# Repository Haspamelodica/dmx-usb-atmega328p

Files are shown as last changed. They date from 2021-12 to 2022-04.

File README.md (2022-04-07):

# DMX-USB interface running on an Atmega328p

This is an Arduino project implementing an USB-DMX interface compatible with [QLC+](https://qlcplus.org/).
It uses a rewritten port of [UDMX](https://github.com/mirdej/udmx) for implementing DMX,
and [VUSB](https://www.obdev.at/products/vusb/index.html) for implementing USB.

You don't need experience with Arduino, C or C++ to build this; I tried to explain every step without requiring prior knowledge in those areas.
However, you do need experience in soldering and building small circuits.

## Split mode

The interface can be used with one or with two Atmegas. Using two Atmegas is called "split mode".
If split mode is disabled, which is the default, the interface will be very choppy.

## Interface variants

There are two variants of the interface, differing in what protocol they use to communicate with the host.
Both can be used with or without split mode.

### UDMX-based interface

This variant works with the the (preinstalled) UDMX plugin of QLC+,
by porting the [UDMX USB-DMX interface]((https://anyma.ch/research/udmx/)) to Atmega328p.

On Windows, the [libusbK driver](https://www.illutzminator.de/udmxdriver.html) needs to be installed for this to work.
This repository contains a copy of the driver software: `uDMX_Driver_libUSBK.zip`.
(If you don't want to install a driver, use the HID-based interface, which works without a driver.)

### HID-based interface

Works with the (preinstalled) HID plugin of QLC+, by using the same protocol
as the [FX5](http://fx5.de/) and [Digital Englightment](http://www.digital-enlightenment.de/usbdmx.htm) USB-DMX interfaces.

The USB and HID communication part of this project is based on the `hid-data` example of VUSB.

## Building the interface

### The circuit

To build the interface, you need to build a small circuit.
The circuit is in `circuit/circuit.fzz` and can be opened with [Fritzing](https://fritzing.org/).
If you don't want to install Fritzing, screenshots are available as well.

#### Split mode

There is no circuit diagram for split mode. However, most of the circuit stays the same, except for the following:
- Add a second Atmega including a clock.
- Connect the RS485 adapter to the Tx output of the second Atmega instead of the first Atmega, and
  connect the Rx input of the second Atmega to the Tx output of the first Atmega.
  
  In other words, insert the second Atmega between the first Atmega's Tx output and the RS485 adapter.

### Compiling firmware

Both interface variants come in the form of Arduino sketches.
This means you can (and should) use the [Arduino software](https://www.arduino.cc/en/software) to compile the interface.
For this, you have to import the sketches into Arduino.
- The easiest way is to copy the `dmx-hid`, `dmx-udmx`, and `libraries` folders into your sketchbook folder.
  (There will probably already be a folder called `libraries` in the sketchbook. In this case, merge both folders.)
- Another way is to temporarily change Arduino's sketchbook path to your local copy of this repository.
  Don't forget where your main sketchbook folder is if you have other projects and want to change back later.
- The ugliest way is to create symlinks. You should only do this if you know what symlinks are.

After importing, the Arduino software will see `dmx-hid` and `dmx-udmx` as regular sketches.
As you probably guessed, `dmx-hid` is the HID-based variant and `dmx-udmx` the UDMX-based one.
You should set the board to "Arduino Uno" (Tools -> Board -> Arduino AVR Boards -> Arduino Uno).
Then, Arduino should be able to compile both variants without problems.

#### Split mode

Import the `dmx-server` sketch as well, like you imported `dmx-hid` and `dmx-udmx`.
This is the sketch running on the second Atmega.

Also, enable `SPLIT_MODE` in `dmxusb-config-common.h`.
See chapter "Configuration and tuning" for details on how to change configuration.

### Burning firmware

I recommend burning the sketches via an ISP programmer. There are plenty of tutorials on how to burn Arduino sketches using ISP.
If you have a regular Arduino board, you can use it as an ISP programmer: see https://www.arduino.cc/en/pmwiki.php?n=Tutorial/ArduinoISP.

Another way is to use the Arduino bootloader.
In this case, you need an USB-to-Serial adapter for burning sketches (once the bootloader is burned).
Again, you can use a regular Arduino board if you have one where the microcontroller can be removed; for example the non-SMD variant of the Uno.
https://docs.arduino.cc/built-in-examples/arduino-isp/ArduinoToBreadboard contains information on how to do this, although not the entire tutorial applies here.

#### Split mode

Burn the `dmx-hid` or `dmx-udmx` sketch to the first Atmega (as without split mode), and the `dmx-server` sketch to the second one.
Keep in mind that the `dmx-hid` and `dmx-udmx` sketches change in behaviour when enabling or disabling split mode,
so you have to re-compile and -burn them as well after en- or disabling split mode.

### Configuration and tuning

All configuration is in `libraries/dmxusb-config` in files starting with `dmxusb-config-`.
In general, "enabling" or "setting" a constant means setting its value to 1,
and "disabling" or "unsetting" means setting the value to 0.

If the interface is choppy, try enabling `ATOMIC_UDRE` in `dmxusb-config-dmx.h`.
This makes DMX transmissions much more reliable; at the cost of more errors on the USB side.
This only makes a difference if you don't use split mode.

## Related links

 - [QLC+](https://qlcplus.org/)
 - [VUSB project website](https://www.obdev.at/products/vusb/index.html)
 - [VUSB sources](https://github.com/obdev/v-usb)
 - [UDMX project website](https://anyma.ch/research/udmx/)
 - [UDMX sources](https://github.com/mirdej/udmx)
 - [FX5 project website](http://fx5.de/) (broken; still accessible in the [Wayback Machine](https://web.archive.org/web/20180828195509/https://fx5.de/))
 - [FX5 standalone software](https://github.com/fx5/usbdmx)

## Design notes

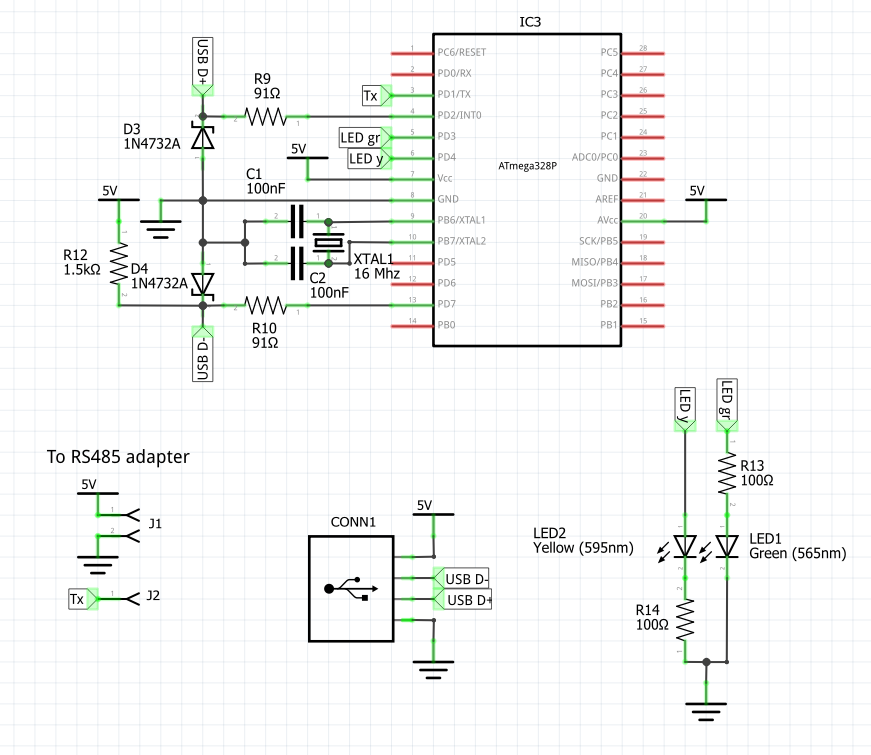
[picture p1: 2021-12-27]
circuit/circuit_schematic.png

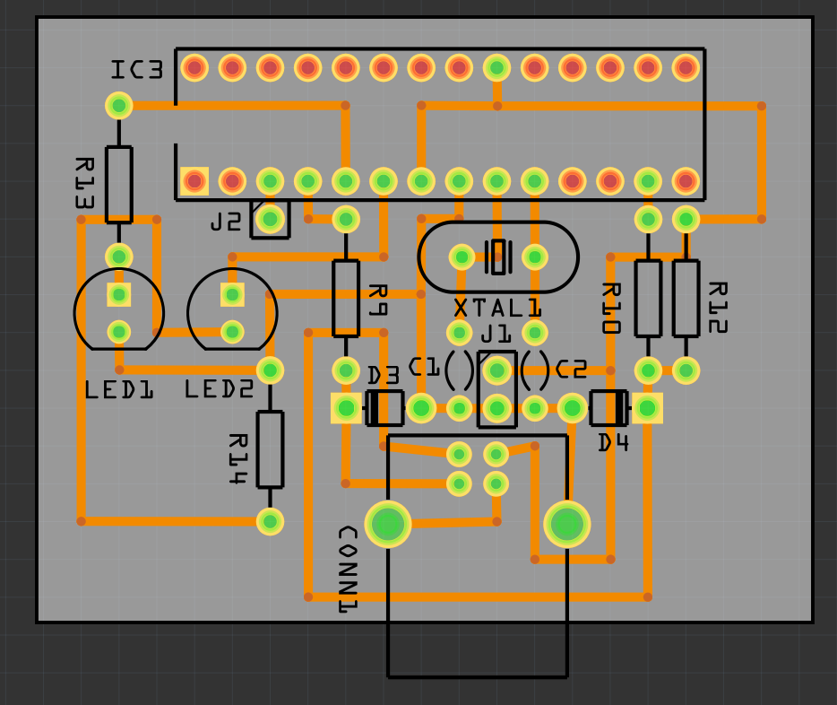
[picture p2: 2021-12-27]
circuit/circuit_board.png

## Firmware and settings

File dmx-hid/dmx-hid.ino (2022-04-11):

/* Name: main.c
   Project: hid-data, example how to use HID for data transfer
   Author: Christian Starkjohann
   Creation Date: 2008-04-11
   Tabsize: 4
   Copyright: (c) 2008 by OBJECTIVE DEVELOPMENT Software GmbH
   License: GNU GPL v2 (see License.txt), GNU GPL v3 or proprietary (CommercialLicense.txt)
*/

#define IS_DMX_CLIENT 1

// ==============================================================================
// includes
// ------------------------------------------------------------------------------

// DMX library
#include <dmxusb-dmx-lib.h>
// HID USB library (includes config)
#include <dmxusb-usb-hid-lib.h>

// AVR Libc (see http://www.nongnu.org/avr-libc/)
#include <avr/io.h>
#include <avr/wdt.h>
#include <avr/interrupt.h>  /* for sei() */
#include <util/delay.h>     /* for _delay_ms() */
#include <avr/eeprom.h>

// debugging
#if DEBUG_ENABLED
#include <dmxusb-debug-lib.h>
#endif

/* ------------------------------------------------------------------------- */
/* ----------------------------- USB interface ----------------------------- */
/* ------------------------------------------------------------------------- */

#pragma GCC diagnostic push
#pragma GCC diagnostic ignored "-Wnarrowing"
PROGMEM const char usbHidReportDescriptor[22] = {    /* USB report descriptor */
    0x06, 0x00, 0xff,              // USAGE_PAGE (Generic Desktop) // incorrect: "Vendor Defined Page 1"
    0x09, 0x01,                    // USAGE (Vendor Usage 1)
    0xa1, 0x01,                    // COLLECTION (Application)
    0x15, 0x00,                    //   LOGICAL_MINIMUM (0)
    0x26, 0xff, 0x00,              //   LOGICAL_MAXIMUM (255)
    0x75, 0x08,                    //   REPORT_SIZE (8)
    0x95, 0x21,                    //   REPORT_COUNT (33)
    0x09, 0x00,                    //   USAGE (Undefined)
    0x92, 0x02, 0x01,              //   OUTPUT (Data,Var,Abs,Buf)
    0xc0                           // END_COLLECTION
};
/* Since we define only one output report, we don't use report-IDs (which
   would be the first byte of the report). The entire report consists of 33
   opaque data bytes.
*/
#pragma GCC diagnostic pop

// ==============================================================================
// Globals
// ------------------------------------------------------------------------------
// usb-related globals
static u08 usb_state;
static u08 usb_length;
static u08 usb_index;
static u08 usb_mode;
static u16 cur_channel;

// LED keep alive counter
static u16 lka_count;

#if DEBUG_ENABLED && DEBUG_DMX_VALUES
static u08 dmx_changed;
#endif

/* ------------------------------------------------------------------------- */

/* usbFunctionRead() is called when the host requests a chunk of data from
   the device. For more information see the documentation in usbdrv/usbdrv.h.
*/
uchar usbFunctionRead(uchar *data, uchar len)
{
  (void) data;
  (void) len;
  // we don't support reading channels.
  return 0xFF;
  /*
  if (usb_state != usb_GetChannelRange) {
    return 0xFF;  // stall if not in good state
  }
  lka_count = 0;

  // update data from stored channels
  len = min(len, end_channel - cur_channel);
  dmx_get_range(cur_channel, len, data);
  cur_channel += len;

#if DEBUG_ENABLED && DEBUG_USB
  dbg_print(F("read"));
  dbg_hexdump(data, len);
  dbg_print('\n');
#endif

  if (cur_channel >= end_channel)
    usb_state = usb_Idle;
  return len;
  */
}

/**
 * Returns 0 on success and 1 on failure.
 */
inline uint8_t handle_written_byte(uint8_t value) {
  switch(usb_state) {
    case usb_NotInitialized:
        // fall-through
    case usb_Idle:
#if DEBUG_ENABLED && DEBUG_PARSING
      dbg_print(F("write in Idle / NotInitialized\n"));
#endif
      // illegal states for a write
      // no need to set usb_state to usb_Idle:
      // if we are in usb_NotInitialized, we want to stay there
      // and if we are in usb_Idle, switching to usb_Idle isn't neccessary
      return 1;
    case usb_InIgnoredBytes:
      // ignore; do nothing
      break;

    case usb_SetReportStart:
#if DEBUG_ENABLED && DEBUG_PARSING
      dbg_print(F("Command: "));
      dbg_print(value);
      dbg_print('\n');
#endif
      if(value < 16) {
        cur_channel = value * BLOCK_SIZE;
        // -1 because the first byte is the command.
        if(cur_channel + usb_length - 1 > NUM_CHANNELS) {
#if DEBUG_ENABLED && DEBUG_PARSING
      dbg_print(F("Error: out of range\n"));
#endif
          // End channel out of range. Shouldn't happen in reality:
          // BLOCK_SIZE = 32, highest block index = 15 => highest start cur_channel = 32 * 15.
          // Report length 33; start byte is command => most data bytes in one report = 32.
          // => maximum required length = 32 * 16 = 512 = NUM_CHANNELS.
          usb_state = usb_Idle;
          return 1;
        }
        usb_state = usb_SetChannelRange;
      } else if(value == cmd_SetMode)
        usb_state = usb_SetMode_ExpectingMode;
      else if(value == cmd_SetTimings || value == cmd_StoreTimings)
        usb_state = usb_InIgnoredBytes;
      else {
        // unknown command
        usb_state = usb_Idle;
        return 1;
      }
      break;

    case usb_SetMode_ExpectingMode:
#if DEBUG_ENABLED && DEBUG_PARSING
      dbg_print(F("Mode: "));
      dbg_print(value);
      dbg_print('\n');
#endif
      if(value & ~mode_mask) {
        // illegal mode
        usb_state = usb_Idle;
        return 1;
      }
      usb_mode = value;
      usb_state = usb_InIgnoredBytes;
      break;

    case usb_SetChannelRange:
#if DEBUG_ENABLED && DEBUG_PARSING
      dbg_print(cur_channel);
      dbg_print(F(": "));
      dbg_print(value);
      dbg_print('\n');
#endif
      dmx_set_channel(cur_channel++, value);
#if DEBUG_ENABLED && DEBUG_DMX_VALUES
      dmx_changed = true;
#endif
      // No need to check if cur_channel is in range
      break;

    default:
#if DEBUG_ENABLED && DEBUG_PARSING
      dbg_print(F("Unknown state\n"));
#endif
      // unknown state
      usb_state = usb_Idle;
      return 1;
  }
  return 0;
}

/* usbFunctionWrite() is called when the host sends a chunk of data to the
   device. For more information see the documentation in usbdrv/usbdrv.h.
*/
uchar   usbFunctionWrite(uchar *data, uchar len)
{
#if DEBUG_ENABLED && DEBUG_USB
  dbg_print(F("write"));
  dbg_hexdump(data, len);
  dbg_print('\n');
#endif

  uint8_t failure = 0;
  
  usb_index += len;
  failure |= usb_index > usb_length;

  // optimization for SetChannelRange
  if(usb_state == usb_SetChannelRange && !failure) {
#if DEBUG_ENABLED && DEBUG_PARSING
      dbg_print(cur_channel);
      dbg_print(F(" - "));
      dbg_print(cur_channel + len);
      dbg_print(':');
      dbg_hexdump(data, len);
      dbg_print('\n');
#endif
    dmx_set_range(cur_channel, len, data);
#if DEBUG_ENABLED && DEBUG_DMX_VALUES
    dmx_changed = true;
#endif
    cur_channel += len;
  }
  else
    for(uint8_t i = 0; i < len && !failure; i ++) {
      // optimization for SetChannelRange
      if(usb_state == usb_SetChannelRange && i < len - 1 && !failure) {
        uint8_t remaining = len - i;
#if DEBUG_ENABLED && DEBUG_PARSING
        dbg_print(cur_channel);
        dbg_print(F(" - "));
        dbg_print(cur_channel + remaining);
        dbg_print(':');
        dbg_hexdump(&data[i], remaining);
        dbg_print('\n');
#endif
        dmx_set_range(cur_channel, remaining, &data[i]);
#if DEBUG_ENABLED && DEBUG_DMX_VALUES
        dmx_changed = true;
#endif
        cur_channel += remaining;
        break;
      }

      failure |= handle_written_byte(data[i]);
    }

  if(failure)
    usb_state = usb_Idle;

  return failure ? 255 : (usb_index == usb_length ? 1 : 0);

/*
  if (usb_state != usb_SetChannelRange) {
    return 0xFF;  // stall if not in good state
  }
  lka_count = 0;

  // update channel values from received data
  len = min(len, end_channel - cur_channel);

  dmx_set_range(cur_channel, len, data);
#if DEBUG_ENABLED && DEBUG_DMX_VALUES
  dmx_changed = true;
#endif
  cur_channel += len;

  if (cur_channel >= end_channel) {
    usb_state = usb_Idle;
    return 1;   // tell driver we've got all data
  }
  return 0;   // otherwise, tell we want still more data
*/
}

/* ------------------------------------------------------------------------- */

usbMsgLen_t usbFunctionSetup(uchar data[8])
{
  // two explicit casts to disable warnings
  usbRequest_t *rq = (usbRequest_t *) (void *) data;

#if DEBUG_ENABLED && DEBUG_USB
  dbg_print(F("setup"));
  dbg_usbrequest(data);
  dbg_print('\n');
#endif

  if ((rq->bmRequestType & USBRQ_TYPE_MASK) == USBRQ_TYPE_CLASS) {  /* HID class request */
    if (rq->bRequest == USBRQ_HID_SET_REPORT) {
      /* since we have only one report type, we can ignore the report-ID */
#if DEBUG_ENABLED && DEBUG_USB
      dbg_print(F("SET_REPORT\n"));
#endif
      usb_index = 0;
      usb_length = rq->wLength.word;
      usb_state = usb_SetReportStart;
      return USB_NO_MSG;  /* use usbFunctionWrite() to receive data from host */
    } else {
#if DEBUG_ENABLED && DEBUG_USB
        dbg_print(F("not SET_REPORT\n"));
#endif
    }
  } else {
    /* ignore vendor type requests, we don't use any */
#if DEBUG_ENABLED && DEBUG_USB
    dbg_print(F("not HID class\n"));
#endif
  }
  return 0;
}

/* ------------------------------------------------------------------------- */

void hadAddressAssigned(void) {
  usb_state = usb_Idle;
  sbi(LED_GREEN_PORT, LED_GREEN_BIT);
  cbi(LED_YELLOW_PORT, LED_YELLOW_BIT);
}

void initForUsbConnectivity()
{
  uchar i = 0;

  /* enforce USB re-enumerate: */
  usbDeviceDisconnect();  /* do this while interrupts are disabled */
  while (--i) {       /* fake USB disconnect for > 250 ms */
    wdt_reset();
    _delay_ms(1);
  }
  usbDeviceConnect();
  usbInit();
}

void init() {
#if DEBUG_ENABLED
  Serial.begin(DEBUG_BAUD);
  dbg_print(F("Init..."));
#endif

  usb_state = usb_NotInitialized;
  lka_count = 0xffff;

  // clear Power On reset flag
  MCUSR &= ~(1 << PORF);

  // configure IO-Ports; most are unused, we set them to outputs to have defined voltages
  DDRB = 0xFF;    // unused
  DDRC = 0xFF;    // unused
  // unused except PD2 / INT0 (used by USB driver),
  // and PD1 (TX) which needs to be an output anyway.
  DDRD = (~(USBMASK) & ~(1 << 2)) & 0xFF;

  // LEDs are now outputs because all unused pins are outputs

  // welcome light
  cbi(LED_GREEN_PORT, LED_GREEN_BIT);
  sbi(LED_YELLOW_PORT, LED_YELLOW_BIT);

  wdt_enable(WDTO_1S);  // enable watchdog timer

  // init usb
  PORTB = 0;        // no pullups on USB pins
  initForUsbConnectivity(); // enumerate device

  dmx_init();

  sei();

#if DEBUG_ENABLED && DEBUG_DMX_VALUES
  dmx_changed = true;
#endif

#if DEBUG_ENABLED
  dbg_print(F(" complete!\n"));
#endif
}

int main()
{
  init();

  for(;;) {              /* main event loop */
    wdt_reset();
    usbPoll();
    dmx_poll();

    // keep yellow led on?
    if (lka_count < 0xfff ) {
      if (lka_count++ == 0)
        sbi(LED_YELLOW_PORT, LED_YELLOW_BIT);
    } else if (lka_count == 0xfff) {
      lka_count++;
      cbi(LED_YELLOW_PORT, LED_YELLOW_BIT);
    }

#if DEBUG_ENABLED && DEBUG_DMX_VALUES
    if (dmx_changed) {
      dbg_print(F("dmx vals"));
      dbg_hexdump(dmx_data, NUM_CHANNELS);
      dbg_print('\n');
      dmx_changed = false;
    }
#endif

  }
  return 0;
}

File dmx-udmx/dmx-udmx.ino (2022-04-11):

// ==============================================================================
// dmx-udmx.ino
// firmware for USB to DMX interface, ported to Atmega328p
//
// License:
// The project is built with AVR USB driver by Objective Development, which is
// published under the GNU General Public License version 2.0 (GPLv2).
// dmx-usb-atmega328p is also distributed under this licence.
//
// target-cpu: ATMega328p @ 16MHz
// ==============================================================================

#define IS_DMX_CLIENT 1

// ==============================================================================
// includes
// ------------------------------------------------------------------------------

// DMX library
#include <dmxusb-dmx-lib.h>
// UDMX USB library (includes config)
#include <dmxusb-usb-udmx-lib.h>

// AVR Libc (see http://www.nongnu.org/avr-libc/)
#include <avr/io.h>     // include I/O definitions (port names, pin names, etc)
#include <avr/pgmspace.h> // include program space (for PROGMEM)
#include <avr/interrupt.h>  // include interrupt support
#include <avr/wdt.h>    // include watchdog timer support

// debugging
#if DEBUG_ENABLED
#include <dmxusb-debug-lib.h>
#endif

typedef struct _midi_msg {
  u08 cn : 4;
  u08 cin : 4;
  u08 byte[3];
} midi_msg;

// ==============================================================================
// Constants
// ------------------------------------------------------------------------------

// device serial number, formatted as YearMonthDayNCounter
PROGMEM const int usbDescriptorStringSerialNumber[] = {USB_STRING_DESCRIPTOR_HEADER(11), '1', '1', '0', '4', '2', '8', 'N', '0', '0', '7', '1'};

// ==============================================================================
// Globals
// ------------------------------------------------------------------------------
// usb-related globals
static u08 usb_state;
static u16 cur_channel, end_channel;
static u08 reply[8];

// LED keep alive counter
static u16 lka_count;

#if DEBUG_ENABLED && DEBUG_DMX_VALUES
static u08 dmx_changed;
#endif

// This descriptor is based on http://www.usb.org/developers/devclass_docs/midi10.pdf
// u
// Appendix B. Example: Simple MIDI Adapter (Informative)
// B.1 Device Descriptor
//
#pragma GCC diagnostic push
#pragma GCC diagnostic ignored "-Wnarrowing"
static PROGMEM const uchar deviceDescrMIDI[] = { /* USB device descriptor */
  18,     /* sizeof(usbDescriptorDevice): length of descriptor in bytes */
  USBDESCR_DEVICE,  /* descriptor type */
  0x10, 0x01,   /* USB version supported */
  0,      /* device class: defined at interface level */
  0,      /* subclass */
  0,      /* protocol */
  8,      /* max packet size */
  USB_CFG_VENDOR_ID,  /* 2 bytes */
  USB_CFG_DEVICE_ID,  /* 2 bytes */
  USB_CFG_DEVICE_VERSION, /* 2 bytes */
  1,      /* manufacturer string index */
  2,      /* product string index */
  0,      /* serial number string index */
  1,      /* number of configurations */
};

// B.2 Configuration Descriptor
static PROGMEM const uchar configDescrMIDI[] = { /* USB configuration descriptor */
  9,      /* sizeof(usbDescrConfig): length of descriptor in bytes */
  USBDESCR_CONFIG,  /* descriptor type */
  101, 0,     /* total length of data returned (including inlined descriptors) */
  2,      /* number of interfaces in this configuration */
  1,      /* index of this configuration */
  0,      /* configuration name string index */
#if USB_CFG_IS_SELF_POWERED
  (1 << 7) | USBATTR_SELFPOWER, /* attributes */
#else
  (1 << 7), /* attributes */
#endif
  USB_CFG_MAX_BUS_POWER / 2,  /* max USB current in 2mA units */

  // B.3 AudioControl Interface Descriptors
  // The AudioControl interface describes the device structure (audio function topology)
  // and is used to manipulate the Audio Controls. This device has no audio function
  // incorporated. However, the AudioControl interface is mandatory and therefore both
  // the standard AC interface descriptor and the classspecific AC interface descriptor
  // must be present. The class-specific AC interface descriptor only contains the header
  // descriptor.

  // B.3.1 Standard AC Interface Descriptor
  // The AudioControl interface has no dedicated endpoints associated with it. It uses the
  // default pipe (endpoint 0) for all communication purposes. Class-specific AudioControl
  // Requests are sent using the default pipe. There is no Status Interrupt endpoint provided.
  /* AC interface descriptor follows inline: */
  9,      /* sizeof(usbDescrInterface): length of descriptor in bytes */
  USBDESCR_INTERFACE, /* descriptor type */
  0,      /* index of this interface */
  0,      /* alternate setting for this interface */
  0,      /* endpoints excl 0: number of endpoint descriptors to follow */
  1,      /* */
  1,      /* */
  0,      /* */
  0,      /* string index for interface */

  // B.3.2 Class-specific AC Interface Descriptor
  // The Class-specific AC interface descriptor is always headed by a Header descriptor
  // that contains general information about the AudioControl interface. It contains all
  // the pointers needed to describe the Audio Interface Collection, associated with the
  // described audio function. Only the Header descriptor is present in this device
  // because it does not contain any audio functionality as such.
  /* AC Class-Specific descriptor */
  9,      /* sizeof(usbDescrCDC_HeaderFn): length of descriptor in bytes */
  36,     /* descriptor type */
  1,      /* header functional descriptor */
  0x0, 0x01,    /* bcdADC */
  9, 0,     /* wTotalLength */
  1,      /* */
  1,      /* */

  // B.4 MIDIStreaming Interface Descriptors

  // B.4.1 Standard MS Interface Descriptor
  /* interface descriptor follows inline: */
  9,      /* length of descriptor in bytes */
  USBDESCR_INTERFACE, /* descriptor type */
  1,      /* index of this interface */
  0,      /* alternate setting for this interface */
  2,      /* endpoints excl 0: number of endpoint descriptors to follow */
  1,      /* AUDIO */
  3,      /* MS */
  0,      /* unused */
  0,      /* string index for interface */

  // B.4.2 Class-specific MS Interface Descriptor
  /* MS Class-Specific descriptor */
  7,      /* length of descriptor in bytes */
  36,     /* descriptor type */
  1,      /* header functional descriptor */
  0x0, 0x01,    /* bcdADC */
  65, 0,      /* wTotalLength */

  // B.4.3 MIDI IN Jack Descriptor
  6,      /* bLength */
  36,     /* descriptor type */
  2,      /* MIDI_IN_JACK desc subtype */
  1,      /* EMBEDDED bJackType */
  1,      /* bJackID */
  0,      /* iJack */

  6,      /* bLength */
  36,     /* descriptor type */
  2,      /* MIDI_IN_JACK desc subtype */
  2,      /* EXTERNAL bJackType */
  2,      /* bJackID */
  0,      /* iJack */
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

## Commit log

2021-12-27 Added circuit
    [circuit.fzz]
2021-12-27 Added LEDs to circuit
    [circuit.fzz]
2021-12-27 Added comment about driver
2021-12-27 Added screenshots of circuit
    [circuit.fzz]
2021-12-27 Fixed library references; fixed some warnings
    [dmx-udmx.ino]
2021-12-29 Fixed timing problem; whitespace changes
    The UDRE handler disabled interrupts for longer
    than the 25 cycles required by VUSB.
    [dmx-hid.ino, dmx-udmx.ino]
2022-03-28 Redesigned project structure; started implementing split mode
    [dmx-hid.ino, dmx-server.ino, dmx-udmx.ino]
2022-04-11 Fixed debug library includes
    [dmx-hid.ino, dmx-server.ino, dmx-udmx.ino]
2022-04-11 Fixed a bug in dmx-hid: first 8 channels were shifted by 2
    [dmx-hid.ino]
